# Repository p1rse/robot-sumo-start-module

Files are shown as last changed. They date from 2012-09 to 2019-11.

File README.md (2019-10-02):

Robot-sumo start module
=====================
Visit http://www.startmodule.com for information of how the start module system works.

This page is mainly for those who are interested in the sourcecode and schematics of the start module.

Purpose
====================
The purpose of this git repository is to maintain the robot-sumo start module system which is an open source and open hardware project.n
The purpose of the module is to make robot-sumo matches more fair and less time consuming by eliminating the possibilites of false starts.
This is done by each robot having a receiver(start module) that are programmed to suply the robot with at start signal when the referee sends the signal via an IR-remote.

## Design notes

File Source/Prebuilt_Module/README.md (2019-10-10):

Read Me
=====================
Hardware version 0.16 is the version that was first sold at RobotChallenge 2012

======================
Programming the device
======================
For those who want to build their own modules based on this code and microcontroller, it is important that the fuse are correct when uploading the hex-file. Incorrect settings may  brick your chip.

Using the following avrdude command is used when programming the prebuilt modules. It utilizes the AvrISP MKII programmer, so if you use any other programmer, change the programming command accordingly. Make sure to be in the correct folder, or replace "StartModule.hex" to the correct path to your hex-file.

avrdude	-pt13 -cavrispmkII -Pusb -u -Uflash:w:StartModule.hex:a -Ulfuse:w:0x79:m -Uhfuse:w:0xef:m

These fuse bits sets the following. The ones marked (important) have the potential to brick your system if set incorrectly. Set them as below and you should be fine:
- No brownout detection
- No clock division by 8
- No Debug wire
- No Eeprom preserve through programming
- No reset disable (important)
- Self Programming enabled (important)
- SPI programming enabled (important)
- Clock source as 4.8MHz, 14CK 64ms startup time (important)
- No watchdog

You can check http://www.engbedded.com/fusecalc for further information about fusebtis.

When the flash has been written, the module will go into "Stopped" state, which means it will blink slowly. Cycle the power and it should be ready to use.

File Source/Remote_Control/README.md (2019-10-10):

Read me
=====================
Hardware version 0.04 is the version that was first used at RobotChallenge 2012

NOTE: When programming, please use the following fusebit settings: E2D7FF when not using an external crystal.
Please visit http://www.engbedded.com/fusecalc to see check what this setting represents.

To program (using pololu stk500 programmer)
avrdude -c stk500 -P/dev/cu.usbmodem002130932 -pm168p -u -Uflash:w:remoteControl.hex -Ulfuse:w:0xe2:m -Uhfuse:w:0xd7:m -Uefuse:w:0xff:m

Note: You might need to change the port and progammer it to work for you

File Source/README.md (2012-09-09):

Source
====================
Generic_ARM - Generic and "easy" to understand code used when connecting IR reciever directly to an ARM microcontroller.

Generic_AVR - Generic and "easy" to understand code used when connecting IR reciever directly to an AVR microcontroller. 

Prebuilt_Module - This is the code loaded on the prebuilt modules, it is hard to understand since it has been optimized to fit in a 1k flash.

Remote_Control - This is the code loaded on the remotes.

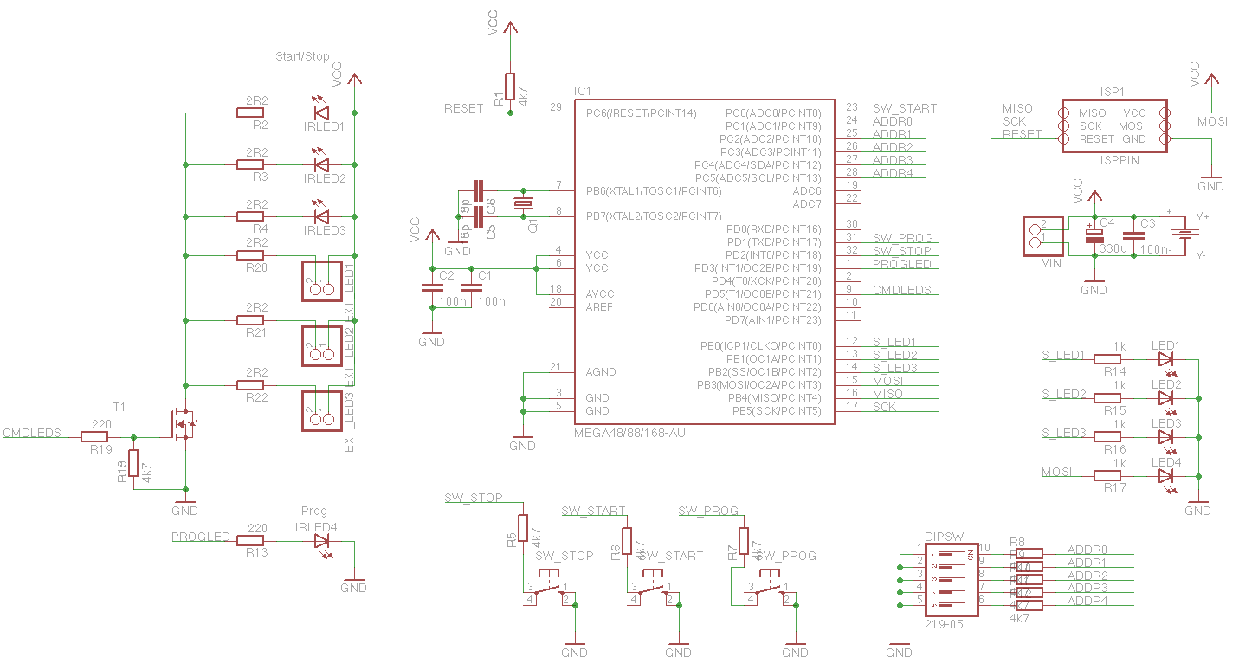
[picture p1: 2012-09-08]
Hardware/Remote_Control/Version_0.04/remote_schematic.png

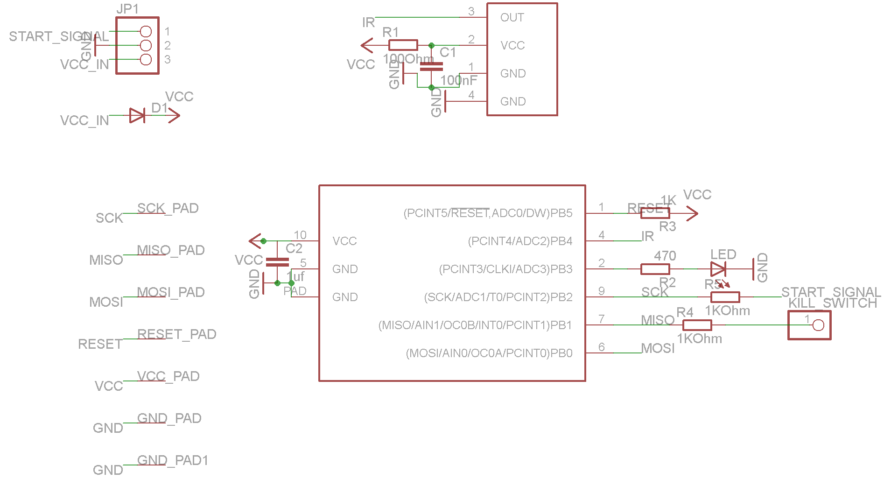
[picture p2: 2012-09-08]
Hardware/Prebuilt_Module/Version_0.16/Schematic_start_module_sumo_IR_V0_16.png

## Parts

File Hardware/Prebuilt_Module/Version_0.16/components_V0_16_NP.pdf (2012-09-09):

Cost

Component | Package | value | Manufacturer | Mouser (part no) | 100.000 | 500.000 | 1000.000 | function
1 | ATTINY13A-MMU | MLF-10 | 556-ATTINY13A-MMU
IR | 1 | IR-receiver
LED | 1 | Green led | 0603 | 859-LTST-C190GKT | LED indications
C1,C2 | 2 | Capacitance | 0603 | 1uf | 810-C1608X7R1C105M
R1 | 1 | Resistance | 0603 | 100ohm | 667-ERJ-3GEYJ101V | to IR-receiver
R2 | 1 | Resistance | 0603 | 470ohm | 667-ERJ-3GEYJ471V
R3,R4,R5 | 3 | Resistance | 0603 | 1kohm | 667-ERJ-3GEYJ102V | pull up for signals out, pull up reset
D1 | 1 | Schottky Diode | SOD523 | 771-RB751S40,115
| | | | | 0.000 | 0.000 | 0.000
| | | | | 0.000 | 0.000 | 0.000

name in
schematic

amount per
board
uC | Atmel | Microcontroller
TSOP75338WTT 1 | Vishay
| | to Microcontroller and IR-receiver
| | resitor for LED
| | reverse polarity protection, as well as some noise cancelation
total (excl VAT)
total (inkl 20% VAT)

Note 1: Mouser doesn't keep this unit in stock, they do however keep TSOP75338WTR
the only difference is how they are packaged in the tape but for pick and place machines this can cause problems.

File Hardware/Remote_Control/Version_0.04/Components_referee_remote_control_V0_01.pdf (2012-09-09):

Sida

Name | Component | Quantity | Mouser article number | Total Price | Comments
B1 | Battery holder, 2xAA | 1 12BH212P-GR | 1.16 | 1.16
C1-C3 | 100nF | 3 581-08055C104J | 0.041 | 0.123
C4 | Capacitor, C6 (ø6.3mm), 330uF | 1 598-AVE337M06X16T-F | 0.083 | 0.083
C5-C6 | 18pF (optional) | 2 140-CC501N180J-RC | 0.053 | 0.106
Q1 | Crystal (optional), HC49S | 1 815-ABL-16-B2 | 0.27 | 0.27
DIPSW | 1 774-2195MST | 0.66 | 0.66
EXT_LED1-EXT_LED3 | 3 649-68000-420HLF | 0.041 | 0.123 20 pins total
IC1 | 1 556-ATMEGA168PA-AU | 2.1 | 2.1
IRLED1 - IRLED4 | 5mm IR LED | 4 78-TSUS5400 | 0.182 | 0.728
ISP | 1 649-67996-420HLF | 0.048 | 0.048 20 pins total
LED1-LED4 | 4 645-598-8170-107F | 0.1 | 0.4 Average price
T1 | MOSFET, N-channel, sot23, 6.5A | 1 621-DMG6968U-7 | 0.454 | 0.454
R1,R5-R12, R18 | 4k7 | 10 667-ERJ-6GEYJ472V | 0.033 | 0.33
R2-R4, R20-R22 | 2R2 | 6 667-ERJ-6GEYJ2R2V | 0.033 | 0.198
R13, R19 | 220 | 2 667-ERJ-6GEYJ221V | 0.033 | 0.066
R14-R17 | 1k | 4 667-ERJ-6GEYJ102V | 0.033 | 0.132
SW_PROG, SW_START, SW_STOP | Tactile switch, SKHHBV, pin, 6x6mm | 3 688-SKHHBV | 0.215 | 0.645
PCB | 1 N/A | 3 | 3 @10pcs
10.626 <-Total

Price (1pcs, €, excl. vat)

Dipswitch, 5 pol
Pinheader, 1x2
Atmega48/88/168-AU

Pinheader, 2x3
Indication LED, 0805, any colour, Vf<3V SOT223 – 771-BUK9880-55135

By sternå

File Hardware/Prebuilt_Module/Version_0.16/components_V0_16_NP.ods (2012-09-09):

 |  |  |  |  |  |  |  | Cost
name in schematic | amount per board | Component | Package | value | Manufacturer | Mouser (part no) | 100.000 | 500.000 | 1000.000 | function
uC | 1 | ATTINY13A-MMU | MLF-10 |  | Atmel | 556-ATTINY13A-MMU |  |  |  | Microcontroller
IR | 1 | TSOP75338WTT 1 |  |  | Vishay |  |  |  |  | IR-receiver
LED | 1 | Green led | 0603 |  |  | 859-LTST-C190GKT |  |  |  | LED indications
C1,C2 | 2 | Capacitance | 0603 | 1uf |  | 810-C1608X7R1C105M |  |  |  | to Microcontroller and IR-receiver
R1 | 1 | Resistance | 0603 | 100ohm |  | 667-ERJ-3GEYJ101V |  |  |  | to IR-receiver
R2 | 1 | Resistance | 0603 | 470ohm |  | 667-ERJ-3GEYJ471V |  |  |  | resitor for LED
R3,R4,R5 | 3 | Resistance | 0603 | 1kohm |  | 667-ERJ-3GEYJ102V |  |  |  | pull up for signals out, pull up reset
D1 | 1 | Schottky Diode | SOD523 |  |  | 771-RB751S40,115 |  |  |  | reverse polarity protection, as well as some noise cancelation
 |  | total (excl VAT) |  |  |  |  | 0.000 | 0.000 | 0.000
 |  | total (inkl 20% VAT) |  |  |  |  | 0.000 | 0.000 | 0.000
 |  | Note 1: Mouser doesn't keep this unit in stock, they do however keep TSOP75338WTR the only difference is how they are packaged in the tape but for pick and place machines this can cause problems.

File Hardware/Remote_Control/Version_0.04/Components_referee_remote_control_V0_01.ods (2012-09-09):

Name | Component | Quantity | Mouser article number | Price (1pcs, €, excl. vat) | Total Price | Comments
B1 | Battery holder, 2xAA | 1 | 12BH212P-GR | 1.16 | 1.16
C1-C3 | 100nF | 3 | 581-08055C104J | 0.041 | 0.123
C4 | Capacitor, C6 (ø6.3mm), 330uF | 1 | 598-AVE337M06X16T-F | 0.083 | 0.083
C5-C6 | 18pF (optional) | 2 | 140-CC501N180J-RC | 0.053 | 0.106
Q1 | Crystal (optional), HC49S | 1 | 815-ABL-16-B2 | 0.27 | 0.27
DIPSW | Dipswitch, 5 pol | 1 | 774-2195MST | 0.66 | 0.66
EXT_LED1-EXT_LED3 | Pinheader, 1x2 | 3 | 649-68000-420HLF | 0.041 | 0.123 | 20 pins total
IC1 | Atmega48/88/168-AU | 1 | 556-ATMEGA168PA-AU | 2.1 | 2.1
IRLED1 - IRLED4 | 5mm IR LED | 4 | 78-TSUS5400 | 0.182 | 0.728
ISP | Pinheader, 2x3 | 1 | 649-67996-420HLF | 0.048 | 0.048 | 20 pins total
LED1-LED4 | Indication LED, 0805, any colour, Vf<3V | 4 | 645-598-8170-107F | 0.1 | 0.4 | Average price
T1 | MOSFET, N-channel, sot23, 6.5A | 1 | 621-DMG6968U-7 | 0.454 | 0.454 | SOT223 – 771-BUK9880-55135
R1,R5-R12, R18 | 4k7 | 10 | 667-ERJ-6GEYJ472V | 0.033 | 0.33
R2-R4, R20-R22 | 2R2 | 6 | 667-ERJ-6GEYJ2R2V | 0.033 | 0.198
R13, R19 | 220 | 2 | 667-ERJ-6GEYJ221V | 0.033 | 0.066
R14-R17 | 1k | 4 | 667-ERJ-6GEYJ102V | 0.033 | 0.132
SW_PROG, SW_START, SW_STOP | Tactile switch, SKHHBV, pin, 6x6mm | 3 | 688-SKHHBV | 0.215 | 0.645
PCB | By sternå | 1 | N/A | 3 | 3 | @10pcs
 |  |  |  |  | 10.626 | <-Total

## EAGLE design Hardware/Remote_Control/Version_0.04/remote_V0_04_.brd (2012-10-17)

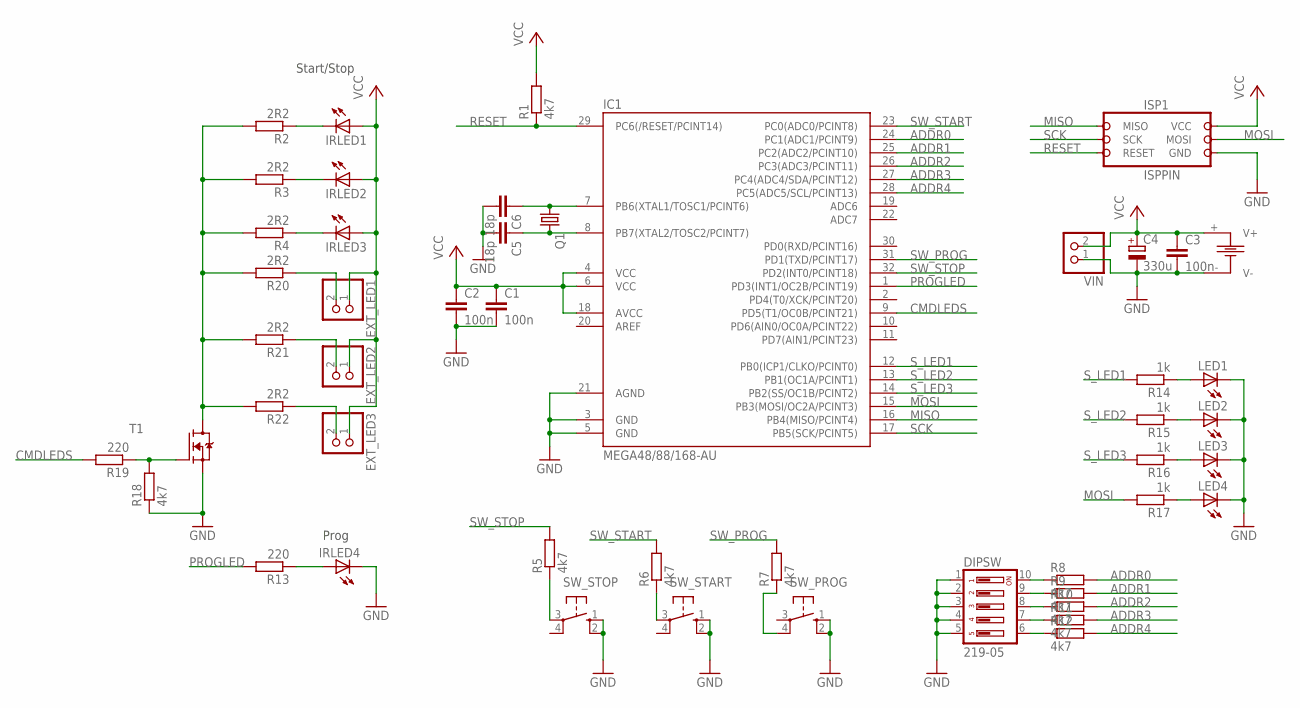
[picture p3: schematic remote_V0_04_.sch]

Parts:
B1: BATTERY_HOLDER_1; BAT_HOLDER_1
C1, C2, C3: 100n; C0805WP
C4: 330u; SANYO-OSCON_SMD_C6
C5, C6: 18p; C0805WP
DIPSW: 219-05; CTS-219-05
EXT_LED1, EXT_LED2, EXT_LED3: PINHD-1X2LONG; 1X2LONG
IC1: MEGA48/88/168-AU; TQFP32-08
IRLED1, IRLED2, IRLED3, IRLED4: LEDLED5MMH; LED5MMH
ISP1: ISPPIN; 2X03
LED1, LED2, LED3, LED4: LED0805; LED_0805
Q1: CRYSTALHC49S; HC49/S
R1, R5, R6, R7, R8, R9, R10, R11, R12, R18: 4k7; R0805WP
R2, R3, R4, R20, R21, R22: 2R2; R0805WP
R13, R19: 220; R0805WP
R14, R15, R16, R17: 1k; R0805WP
SW_PROG: 10-XX; B3F-10XX
SW_START: 10-XX; B3F-10XX
SW_STOP: 10-XX; B3F-10XX
T1: MOSFET_N_SOT23; SOT23
VIN: PINHD-1X2; 1X02

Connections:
ADDR0: IC1.24 (PC1(ADC1/PCINT9)), R8.2
ADDR1: IC1.25 (PC2(ADC2/PCINT10)), R9.2
ADDR2: IC1.26 (PC3(ADC3/PCINT11)), R10.2
ADDR3: IC1.27 (PC4(ADC4/SDA/PCINT12)), R11.2
ADDR4: IC1.28 (PC5(ADC5/SCL/PCINT13)), R12.2
CMDLEDS: IC1.9 (PD5(T1/OC0B/PCINT21)), R19.2
GND: B1.- (V-), C1.2, C2.2, C3.2, C4.-, C5.2, C6.2, DIPSW.1, DIPSW.2, DIPSW.3, DIPSW.4, DIPSW.5, IC1.3 (GND), IC1.5 (GND), IC1.21 (AGND), IRLED4.P$2 (C), ISP1.6 (GND), LED1.C, LED2.C, LED3.C, LED4.C, R18.1, SW_PROG.1 (S), SW_PROG.2 (S1), SW_START.1 (S), SW_START.2 (S1), SW_STOP.1 (S), SW_STOP.2 (S1), T1.2 (S), VIN.1
MISO: IC1.16 (PB4(MISO/PCINT4)), ISP1.1 (MISO)
MOSI: IC1.15 (PB3(MOSI/OC2A/PCINT3)), ISP1.4 (MOSI), R17.2
unnamed: IRLED1.P$2 (C), R2.1
unnamed: IRLED2.P$2 (C), R3.1
unnamed: IRLED3.P$2 (C), R4.1
unnamed: DIPSW.10, R8.1
unnamed: DIPSW.9, R9.1
unnamed: DIPSW.8, R10.1
unnamed: DIPSW.7, R11.1
unnamed: DIPSW.6, R12.1
unnamed: R5.1, SW_STOP.3
unnamed: R6.1, SW_START.3
unnamed: R7.1, SW_PROG.4 (P1)
unnamed: IRLED4.P$1 (A), R13.1
unnamed: R18.2, R19.1, T1.1 (G)
unnamed: LED1.A, R14.1
unnamed: LED2.A, R15.1
unnamed: LED3.A, R16.1
unnamed: LED4.A, R17.1
unnamed: C6.1, IC1.7 (PB6(XTAL1/TOSC1/PCINT6)), Q1.1
unnamed: EXT_LED1.2, R20.1
unnamed: EXT_LED2.2, R21.1
unnamed: R2.2, R3.2, R4.2, R20.2, R21.2, R22.2, T1.3 (D)
unnamed: EXT_LED3.2, R22.1
unnamed: C5.1, IC1.8 (PB7(XTAL2/TOSC2/PCINT7)), Q1.2
PROGLED: IC1.1 (PD3(INT1/OC2B/PCINT19)), R13.2
RESET: IC1.29 (PC6(/RESET/PCINT14)), ISP1.5 (RESET), R1.1
SCK: IC1.17 (PB5(SCK/PCINT5)), ISP1.3 (SCK)
SW_PROG: IC1.31 (PD1(TXD/PCINT17)), R7.2
SW_START: IC1.23 (PC0(ADC0/PCINT8)), R6.2
SW_STOP: IC1.32 (PD2(INT0/PCINT18)), R5.2
S_LED1: IC1.12 (PB0(ICP1/CLKO/PCINT0)), R14.2
S_LED2: IC1.13 (PB1(OC1A/PCINT1)), R15.2
S_LED3: IC1.14 (PB2(SS/OC1B/PCINT2)), R16.2
VCC: B1.+ (V+), C1.1, C2.1, C3.1, C4.+, EXT_LED1.1, EXT_LED2.1, EXT_LED3.1, IC1.4 (VCC), IC1.6 (VCC), IC1.18 (AVCC), IRLED1.P$1 (A), IRLED2.P$1 (A), IRLED3.P$1 (A), ISP1.2 (VCC), R1.2, VIN.2

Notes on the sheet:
Start/Stop
Prog

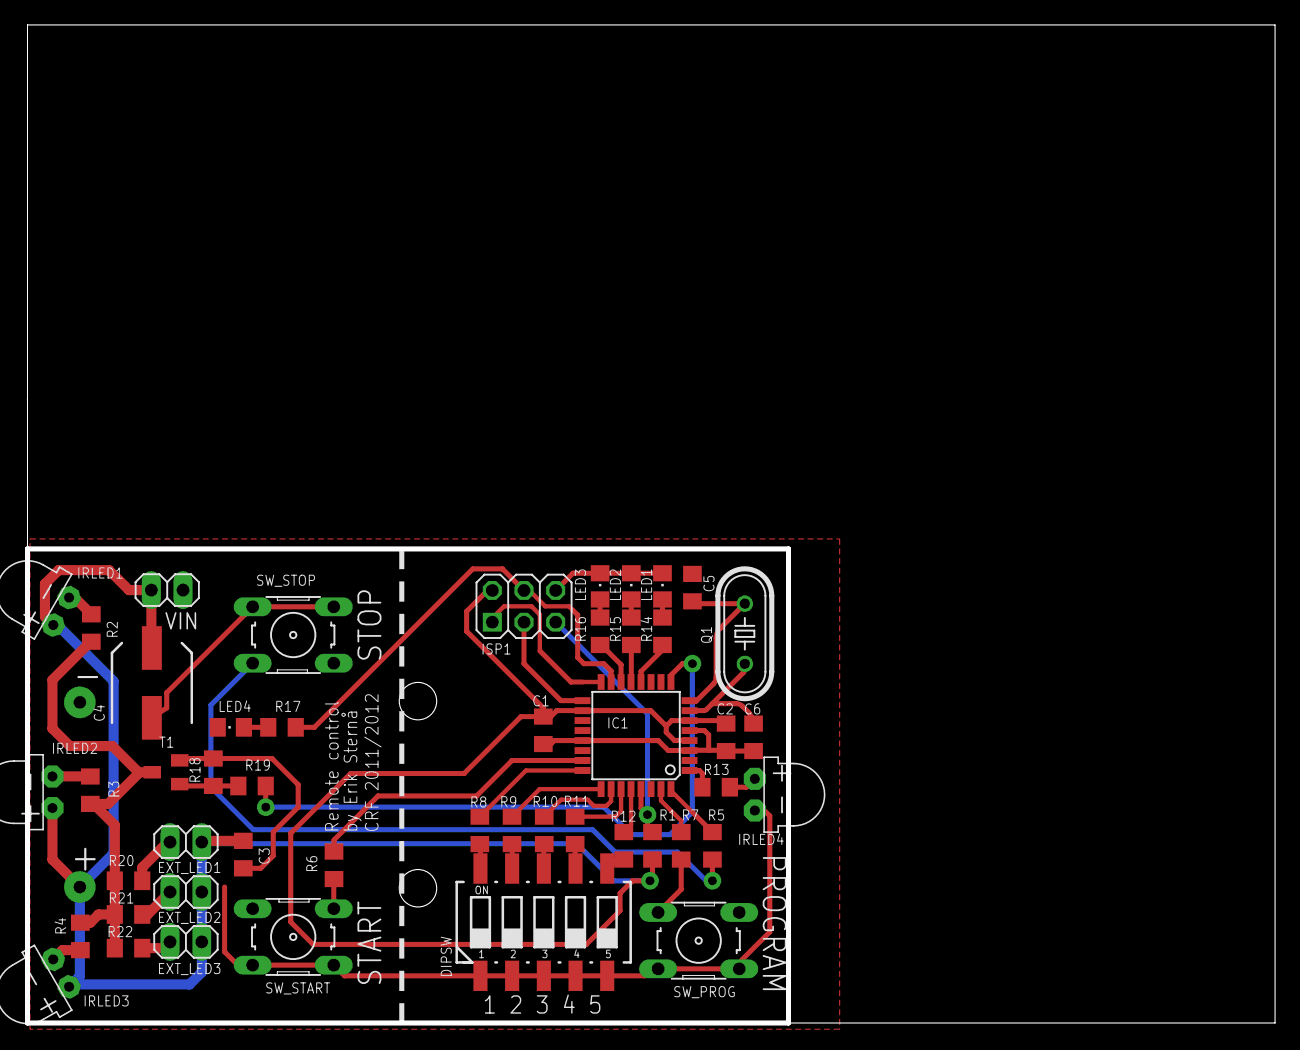
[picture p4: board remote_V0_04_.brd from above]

Board: 2 copper layers, 100.0 x 80.0 mm, 49 parts (1 on the bottom side), 42 nets.

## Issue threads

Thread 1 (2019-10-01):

Too much power consumption of  the remote in sleep mode

drykov, 2019-10-01:
When power up the remote consumes appropriate 0.4uA at 3v.
After the first press of any button it tries to go to sleep, but the current consumption keeps at relatively high 180uA.
It happens because after measuring of the battery voltage the ADC is left in enabled state.
Probably it could be fixed by disabling ADC by adding
	ADCSRA &= ~_BV(ADEN); // disable ADC after measurement to stop draining power
at line 279 in main.c file.

p1rse, 2019-10-02:
Hi Drykov.
This sounds like a great improvement!
I have noticed that the remote seem to deplete batteries a bit faster than desired.
Are you able to program a remote and test it yourself?
Best Regards

drykov, 2019-10-02:
I tried a proposed fix and it seems good. I put updated sources and the hex built with Atmel Studio 7 at https://github.com/drykov/robot-sumo-start-module (master for your master and InfiniteStart branch for repetition settings used in the originally published hex) for our robotics team.
Unfortunately I'm not an expert in AVR so you have to verify it on you own.

p1rse, 2019-11-27:
I have verified the fix and it is now merged, god job Drykov!

Closed 2019-11-27.

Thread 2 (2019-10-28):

Module is always in start mode

relativy, 2019-10-28:
Hi guys,
I have problem with 3 modules i have put in 3 my sumo standard robots.
They are not responding to any comands, and stay in start mode all the time.
One module suffer a damage to IR recevier during the competition. I have replace it.
Other to, did not suffer any physical damage, just suddenly stopped working.
Did anyone have any idea, what can be wrong, and how to fix it?

p1rse, 2019-10-28:
Hi Relativy.
The module will retain the last state so you have to press stop (light will start to blink) then reset your robot and it will be back to initial state. To help you further please answer the following:
What type of remote are you testing with?
Are the module put in home mode or not?
Best Regards

relativy, 2019-10-28:
HI, i am testing with Sumo Remote app from my phone. I guess now i need to chcek all channels, to find out, witch one will stop the module.

p1rse, 2019-10-28:
You should be able to send the programming signal, this should be received in the started mode.

p1rse, 2019-10-28:
As you can see here: https://p1r.se/startmodule/implement-yourself/modes-of-operation/
The comment for (4) is just to handle this case.

relativy, 2019-10-28:
The programing signal also did not work, and it looks like there is no way to reset the modules.
It is also possible that IR recivers are damaged, but I have no way to chceck that out, and it seems unlikely that 3 of them would get damaged.

p1rse, 2019-10-28:
hmm ok, It could be the MCU or Reciever that is dead. If it has happened to 3 modules in the same robot it might be the robot that is killing them? There is a diode on the module to protect the MCU however in Standard sumo there can be very high current and disturbances from the powerful motors. Have you had issues with any other Electronics in your robot. Did the startmodules die during a fight or when high currents have been involved?

relativy, 2019-10-28:
The modules were used i 2 diffrent sumo robots, with diffrent controlers. One is AVR other is STM.
I dont think motors really have anything to do with that. Logic and Power section are separated opticaly and have their own batteries. So only EM Field fluctuation can generate any interference, but even analog section for sensors hardly show any signs of interferece during fights.

2 modules died during fight. 1 of them was hit by other robot and the IR reciver was cut out (board is fine). The other died also during fight but with no aparent reason. Third module was locked when I arrived at the competition, so I dont really know when it get stuck in start mode.

p1rse, 2019-10-28:
Ok, I understand. Hard to know what the root cause is, normally the modules are robust.
Are you sure your app is sending commands via IR?
Do you have a normal TV remote that uses RC-5 protocol?
If yes you could try to put the modules in "home mode" and see if it works.

relativy, 2019-10-28:
Honestly I can't be sure if App is sending signal, but it worked before, so i do not expect any issues here.
I need to check my TV, maybe yes. But i still have a quesion. In order to reset the module do I need to send programing signal at the same channel that the module is set? or program it at any channel and it will reset?

p1rse, 2019-10-28:
The programming command does not have to be the same channel. It should reset when it receives the programming signal regardless of channel.

relativy, 2019-10-28:
I could not find RC5 TV pilot, but i found another module, so my phone working fine.
I guess the problem is the IR reciver. I will order new ones, replace in all modules and see if it will work,
becouse nothing elese came to my mind, ant they were to exposed during competition.

p1rse, 2019-10-28:
Ok, let us know if you find the root cause for your issue.

relativy, 2019-11-15:
The spare IR recivers just arrived. I have swaped them, and all my modules working fine now.

p1rse, 2019-11-27:
Good to know, I will close this issue but keep an eye and ear open if we get similar report.
If you find out the root cause please let us know.

Closed 2019-11-27.

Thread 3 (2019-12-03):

New hex does not turn on IR programming LED

andreikovari, 2019-12-03:
I've made a pair of custom remotes and when I tried to upload the last pushed hex, the programming LED does not flicker. The start/stop ones flicker, but I can't check it on a module, since I can't program it to the new address. The fuse bits are E2D7FF
I'll try to use the oscilloscope to check the output on the start/stop LEDs

p1rse, 2019-12-03:
If you checkout the previous version of the hex file (1.0) instead of new version (1.01), are you then able to program?

andreikovari, 2019-12-03:
I've uploaded the 1.0, still nothing. Checked with the oscilloscope, no output on the programming LED

andreikovari, 2019-12-03:
Also, I forgot to mention that the visible LEDs seem to work ok

p1rse, 2019-12-04:
Hi, it sounds like there is some HW issue in your custom remote since the 1.0 for sure works on the existing remotes.

andreikovari, 2019-12-04:
The hardware is the same (schematic wise). I have an older version that worked, but I lost the old hex.
Now, the new code, does not work. Neither on the previous version or the new one.
Could it be a compiling or fusebits issue?

andreikovari, 2019-12-04:
Could it be that I can't compile it using atmega168pa option, and I have selected instead atmega168p?
"unknown MCU 'atmega168pa' specified"

andreikovari, 2019-12-04:
This issue is solved.
The dipswitches I use had a default off state when were shipped (and also masked with a capton tape for reflow soldering). And since I wanted to give them to the user "untouched" I never removed the tape or changed the dipswitches.
And my guess (I'll look into the code too) is that with all the dipswitches turned off, it can't select an address, so the programming LED does not flicker.

p1rse, 2019-12-04:
Ah good that you found the root cause. ID 0 and 1 is reserved so that is probably the issue. In ID 0 the referee remote work as a TV remote to test the home mode. You can see more details here https://p1r.se/startmodule/for-organizers/referees-remote/

andreikovari, 2019-12-04:
So, I've tested with various versions of the code, they all work. The dipswitches caused the problem.
The issue can be closed. Thank you for all the support!

Closed 2019-12-05.

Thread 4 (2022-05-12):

Prebuilt module makefile F_CPU wrong

Eryk-Mozdzen, 2022-05-12:
Hi,
in prebuilt module makefile the default F_CPU value is wrong.

ATtiny13A can't work on internal 8MHz oscillator because it does not exist (4,8MHz, 9.6MHz or 128 kHz available).
With the proposed fuse bits configuration only changing from CLOCK=8000000 to CLOCK=4800000 made this module work.

I want to put this here because it takes me few hours of debugging my hardware to find what is the issue.

p1rse, 2022-05-20:
Hello Eryk
Thanks you for the input!
I have corrected the file.
Best Regards

Closed 2022-05-20.

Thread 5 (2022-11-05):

Compiled .hex differs from original

andreikovari, 2022-11-05:
I'm trying to generate a new hex (on windows) with make and the newly generated code is 1204Bytes
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
Are there any notes regarding the used compiler or was the makefile updated?

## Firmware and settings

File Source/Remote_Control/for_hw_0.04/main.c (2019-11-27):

/*
 * main.c
 *
 *  Created on: 13 aug 2010
 *      Author: benjamin and sterna
 */

#include "main.h"

volatile unsigned char buttonPressed=0;

int main(void)
{
	//Init stuff
	clock_prescale_set(0);
	initIR();
	initSW();
	initLed();

	while(1)
	{
		if (buttonPressed == STOP)
		{
			//debounce
			while(SW_STOP)
			{
				_delay_ms(10);
				while(SW_STOP)	//Commands will be sent as long as button is held
				{
					sendStop(1);
				}
				//wait until button is released, to avoid sending unintentional commands
				while(SW_STOP){}
				_delay_ms(10);
			}
			_delay_ms(100);
		}
		else if (buttonPressed == START)
		{
			//debounce
			while(SW_START)
			{
				_delay_ms(10);
				if (SW_START)	//Start commands will be sent a set number of times, in quick succession
				{
					sendStart(3);
				}
				//wait until button is released, to avoid sending unintentional commands
				while(SW_START){}
				_delay_ms(10);
			}
			_delay_ms(100);
		}
		else if(buttonPressed == PROG)
		{
			//debounce
			while(SW_PROG)
			{
				_delay_ms(10);
				if (SW_PROG)	//Programming command will be sent only once, to minimize the risk of unintentional programming
				{
					sendProgCmd();
				}
				//wait until button is released, to avoid sending unintentional commands
				while(SW_PROG){}
				_delay_ms(10);
			}
			_delay_ms(200);
		}
		goToSleep();
	}


	//Used for testing the control (does not rely on the power-down functions)
	while(1)
	{
		if (SW_STOP)
		{
			//debounce
			_delay_ms(10);
			if(SW_STOP)
			{
				sendStop(20);
			}
			//wait until button is released, to avoid sending unintentional commands
			while(SW_STOP){}
			_delay_ms(200);
		}
		else if (SW_START)
		{
			//debounce
			_delay_ms(10);
			if (SW_START)
			{
				sendStart(20);
			}
			//wait until button is released, to avoid sending unintentional commands
			while(SW_START){}
			_delay_ms(200);
		}
		else if(SW_PROG)
		{
			//debounce
			_delay_ms(10);
			if (SW_PROG)
			{
				sendProgCmd();
			}
			//wait until button is released, to avoid sending unintentional commands
			while(SW_PROG){}
			_delay_ms(200);
		}

	}
	return 0;
}

/*
 * Send the programming command, using the current dip-switch setting
 */
void sendProgCmd()
{
	const unsigned char id = readDip();
	//Only send prog-command if valid address
	if (id>1)
	{
		setLed(1,ON);
		send_packet(RC5_ADR_PROGRAMMING,id<<1,PROGLED);
		_delay_ms(300);
		setLed(1,OFF);
		_delay_ms(300);
	}
	else
	{
		//Warn the user if he/she uses id 0 or 1
		setLed(1,ON);
		_delay_ms(300);
		setLed(1,OFF);
		_delay_ms(300);
		setLed(1,ON);
		_delay_ms(300);
		setLed(1,OFF);
		_delay_ms(300);
	}
}

/*
 * Sends the start command using the current dip-switch setting
 * The command is repeated at frequency set in main.h intervals "repeats" number of times
 * Repeats = 0 gives one message
 */
void sendStart(unsigned char repeats)
{
	const unsigned char id = readDip();
	if(id==1)
	{
		//Warn the user if he/she uses id 1
		setLed(3,ON);
		_delay_ms(300);
		setLed(3,OFF);
		_delay_ms(300);
		setLed(3,ON);
		_delay_ms(300);
		setLed(3,OFF);
		_delay_ms(300);
	}
	else
	{
		setLed(3,ON);
		repeats++;
		while(repeats)
		{
			setLed(4,ON);
			//Home-mode
			if(id==0)
			{
				send_packet(RC5_ADR_CAMCORDER,RC5_CMD_1,CMDLED);
			}
			else
			{
				send_packet(RC5_ADR_EXPERIMENTAL,(id<<1 | 0b00000001),CMDLED);
			}
			setLed(4,OFF);
			_delay_ms(30);	//Start commands should be sent in quick succession
			repeats--;
		}
		setLed(3,OFF);
	}
}

/*
 * Sends the stop command using the current dip-switch setting
 * The command is repeated at a frequency set in main.h intervals "repeats" number of times
 * Repeats = 0 gives one message
 */
void sendStop(unsigned char repeats)
{
	const unsigned char id = readDip();
	if(id==1)
	{
		//Warn the user if he/she uses id 1
		setLed(2,ON);
		_delay_ms(300);
		setLed(2,OFF);
		_delay_ms(300);
		setLed(2,ON);
		_delay_ms(300);
		setLed(2,OFF);
		_delay_ms(300);
	}
	else
	{
		setLed(2,ON);
		repeats++;
		while(repeats)
		{
			setLed(4,ON);
			//Home-mode
			if(id==0)
			{
				send_packet(RC5_ADR_CAMCORDER,RC5_CMD_2,CMDLED);
			}
			else
			{
				send_packet(RC5_ADR_EXPERIMENTAL,(id<<1 & 0b11111110),CMDLED);
			}
			setLed(4,OFF);
			_delay_ms(REPETITION_FREQ);
			repeats--;
		}
		setLed(2,OFF);
	}

}

/*
 * Prepares the remote for power-down mode (to save power)
 * Turns off more or less everything, thus drawing less than 1µA in power-down.
 * When it wakes up, it checks the battery voltage and signals
 * a low-battery state by blinking all leds repeatedly, then going back to sleep
 * Please note that no command will be sent in a low-battery state
 */
void goToSleep()
{
	//Turn off the following modules: all
	PRR |= _BV(PRTWI) | _BV(PRTIM2) | _BV(PRTIM0) | _BV(PRTIM1) | _BV(PRSPI) | _BV(PRUSART0) | _BV(PRADC);
	//Disconnect pullups on dipswitch
	PORTC &= 0b11000001;
	//Enable interrupt on pinchange PINC0, PIND1 and int0 (low-level interrupt)
	EICRA &= ~_BV(ISC00) & ~_BV(ISC01);
	EIMSK |= _BV(INT0);
	PCICR |= _BV(PCIE1) | _BV(PCIE2);
	PCMSK2 |= _BV(PCINT17);
	PCMSK1 |= _BV(PCINT8);

	sei();
	//Sleep (power down)
	SMCR |= _BV(SM1) | _BV(SE);
	asm("sleep");
	SMCR &= ~_BV(SE);
	cli();

	/*
	 * The voltage measurement is a little weird
	 * By using the battery voltage directly as vcc to the microcontroller
	 * one can measure the internal 1.1V reference, using vcc as analog reference voltage
	 * and thereby indirectly measure the battery voltage.
	 * The ADC value will increase as the battery voltage drops, hence the if(ADCH > LOW_VOLTAGE)
	 * If the battery is fine, it continues based on the button pressed
	 */
	PRR &= ~_BV(PRADC);
	ADMUX |= _BV(REFS0) | _BV(ADLAR) | 0b00001110;
	ADCSRA |= _BV(ADEN);
	//Wait for internal 1.1V reference to stabilize
	_delay_ms(5);
	ADCSRA |= _BV(ADSC);
	while(!(ADCSRA & _BV(ADIF))){}
	ADCSRA |= _BV(ADIF);
    ADCSRA &= ~_BV(ADEN); // disable ADC after measurement to stop draining power

	if (ADCH > LOW_VOLTAGE)
	{
		setAllLeds(ON);
		_delay_ms(300);
		setAllLeds(OFF);
		_delay_ms(300);
		setAllLeds(ON);
		_delay_ms(300);
		setAllLeds(OFF);
		_delay_ms(300);
		setAllLeds(ON);
		_delay_ms(300);
		setAllLeds(OFF);
		_delay_ms(300);
		//This might cause a stack overflow if a button is pressed repeatedly in a battery-low state
		//However, this needs something like 100-200 button presses.
		goToSleep();
	}
	//Restore Timer0 and 2, set pullups on dip switch
	PRR &= ~_BV(PRTIM2) & ~_BV(PRTIM0);
	PORTC |= 0b001111110;
}

//Wake up on start button
ISR(PCINT1_vect)
{
	buttonPressed = START;
}

//Wake up on prog button
ISR(PCINT2_vect)
{
	buttonPressed = PROG;
}

//Wake up on stop button, low level
ISR(INT0_vect)
{
	buttonPressed = STOP;
}

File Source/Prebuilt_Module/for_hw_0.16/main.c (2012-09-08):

/*
 * main.c
 *
 *  Created on: 18 nov 2011
 *      Author: Sterna, Benjamin
 *
 *  NOTE:
 *  This code looks like crap, but it had to be optimized to save
 *  enough bytes to fit on this processor.
 *
 */


#include <avr/io.h>
#include <util/delay.h>
#include <avr/interrupt.h>
#include <avr/eeprom.h>

#include "ir.h"

/*
 * EEPROM addresses
 */
#define E_STATE_ADDRESS		8
#define E_STOPCMD_ADDRESS	10

/*
 * Pins
 */
#define LEDPIN		3
#define STARTPIN	2
#define KILLSWPIN	1
#define MODEPIN		0

/*
 * States
 */
#define POWERON			1
#define STARTED			2
#define STOPPED_SAFE	3
#define STOPPED			4

/*
 * Home mode commands
 */
#define HOME_START	RC5_CMD_1
#define HOME_STOP	RC5_CMD_2

/*
 * Default stop command (used after programming when eeprom is cleared)
 */
#define DEFAULT_STOP_CMD	0x04

/*
 * IO Macros
 */
#define LED_ON()		(PORTB |= _BV(LEDPIN))
#define LED_OFF()		(PORTB &= ~_BV(LEDPIN))
#define IS_COMP_MODE	(PINB & _BV(0))
//#define IS_COMP_MODE	(1) // Permanent competition mode

/*
 * Calling this function requires less memory than using _delay_ms
 * in several places.
 */
void delay_500() {
	_delay_ms(500);
}

// Using a function and function calls takes less memory..
void eeprom_write_byte_cli(unsigned char address, unsigned char state) {
	cli();
	eeprom_write_byte((unsigned char*)(unsigned int)address, state);
	sei();
}

int main() {
	ir_init();

	unsigned char currentState = eeprom_read_byte((unsigned char*)E_STATE_ADDRESS);
	unsigned char stopCommand = eeprom_read_byte((unsigned char*)E_STOPCMD_ADDRESS);
	unsigned char savedState = currentState;

	DDRB = _BV(LEDPIN) | _BV(KILLSWPIN) | _BV(STARTPIN);
	PORTB = _BV(MODEPIN); // Pull-up on mode select pin

	sei();

	for(;;) {
		while(!has_next) {
			switch (currentState) {
			case POWERON:
				PORTB = _BV(MODEPIN) | _BV(KILLSWPIN);
				break;

			case STARTED:
				PORTB = _BV(STARTPIN) | _BV(LEDPIN) | _BV(KILLSWPIN) | _BV(MODEPIN);
				break;

			case STOPPED_SAFE:
				PORTB = _BV(MODEPIN);
				eeprom_write_byte_cli(E_STATE_ADDRESS, STOPPED_SAFE);
				delay_500();
				delay_500();
				currentState = STOPPED;
				has_next = 0;
				break;

			case STOPPED:
				PORTB = _BV(MODEPIN);
				eeprom_write_byte_cli(E_STATE_ADDRESS, POWERON);
				for (;;) {
					LED_ON();
					delay_500();
					delay_500();
					LED_OFF();
					delay_500();
					delay_500();
				}
				break;

				// When eeprom is undefined we might end up here (after programming)
			default:
				currentState = STOPPED;
				stopCommand = DEFAULT_STOP_CMD;
				break;
			}

			if (savedState != currentState && currentState != STOPPED) {
				eeprom_write_byte_cli(E_STATE_ADDRESS, currentState);
				delay_500();
				savedState = currentState;
			}
		}
		has_next = 0;

		if (addr == RC5_ADR_PROGRAMMING) {
			stopCommand = cmd & 0b11111110;
			LED_ON();
			delay_500();
			eeprom_write_byte_cli(E_STOPCMD_ADDRESS, stopCommand);
			LED_OFF();
			delay_500();
			LED_ON();
			delay_500();
			LED_OFF();
			has_next = 0;
			currentState = POWERON;
		} else {
			switch (currentState) {
				case POWERON:
				if (IS_COMP_MODE) {
					if (addr == RC5_ADR_EXPERIMENTAL) {
						if (cmd == (stopCommand + 1)) {
							currentState = STARTED;
						} else if (cmd == stopCommand) {
							currentState = STOPPED_SAFE;
						}
					}
				} else {
					if (cmd == HOME_START) {
						currentState = STARTED;
					} else if (cmd == HOME_STOP) {
						currentState = STOPPED_SAFE;
					}
				}
				break;

			case STARTED:
				if (IS_COMP_MODE) {
					if (addr == RC5_ADR_EXPERIMENTAL) {
						if (cmd == stopCommand) {
							currentState = STOPPED_SAFE;
						}
					}
				} else {
					if (cmd == HOME_STOP) {
						currentState = STOPPED_SAFE;
					}
				}
				break;
			}
		}
	}

	return(0);
}

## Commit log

2012-09-08 added files that previoulsy was on the homepage
    [Schematic_start_module_sumo_IR_V0_16.brd, Schematic_start_module_sumo_IR_V0_16.sch, remote_V0_04_.brd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]
2012-09-08 rename folder and updating som read me files
    [Schematic_start_module_sumo_IR_V0_16.brd, Schematic_start_module_sumo_IR_V0_16.sch, remote_V0_04_.brd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]
2012-09-09 Drill sizes for battery holder updated
    Drill sizes for the holes on the battery holder were to small. Changed
    from 0.8 mm to 1.0 mm.
    Also added some files to .gitignore.
    [remote_V0_04_.brd, remote_V0_04_.sch]
2012-09-09 Added component lists in open office format
    [Components_referee_remote_control_V0_01.ods, components_V0_16_NP.ods]
2012-10-17 Repetition updated
    Updated the software of the remote control. Updated 2 things:
    - Start and stop commands are sent as while button is held, thus making
    it easier to stop the robots
    - Set the repetition frequency to 114ms, which is standard for RC5. It
    can be set in main.h
2012-10-17 Produced new gerber files
    [remote_V0_04_.brd]
2013-02-24 Description of fusebits for ATtiny13A
    Added a guide on how to set the program the chip when used the
    precompiled program if you build your own module using an ATtiny13A
    (check the Readme at Source/Prebuilt_Module).
2013-03-27 Changed repetition frequency (again) Changed how the start commands are sent. using the last revisions code, a situation could happen where one robot starts a long time after the other, which would l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
2019-10-11 Renamed hex file to include FW version and which HW version they are built for FW 1.0 are the current version that was already in the repo
2019-11-27 Verified fix for discharge bug in Referee remote as identified and proposed by Drykov. Verified that current in stand-by(after pressing a button) before bug fix was 0.21mA and after the bugfix 0.01mA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
    [main.c]
